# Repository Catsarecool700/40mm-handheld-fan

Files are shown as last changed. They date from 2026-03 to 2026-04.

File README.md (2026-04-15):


Measuring only 40x63x68 its a tiny little pain in the ass to solder and put together, mostly because of the 20 tiny fiddly wires that go everywhere but its really cute and loud so thats all that matters

The code is a mess but functions and the cad is (probably) final 

- Electronics required 
  - Esp32 s3 super mini
  - Mini360 or similar buck converter
  - 128x32 0.92" i2c oled
  - PSP 1000 joystick (the one with pads on the bottom)
  - USBc Trigger board either adjustable or set to 12v
  - Delta [GFC0412D](https://www.delta-fan.com/Download/Spec/GFC0412DS-SM06B0G.pdf) 
  - A diode may be needed if your buck converter lacks one to prevent voltage backflow when programing the esp32
- Hardware required
  - M2x3x3.2 heatset insert X4
  - M2x8 cap head bolt X2
  - M2x3 button head bolt X2
  - M3x25 cap head bolt X4
  - Hot glue gun
- Future plans
  - Website for remote control over wifi
  - Better oled ui with proper menus and a nicer look
  - Mk ii using an even louder and faster spinning fan in the same footprint 

 
 


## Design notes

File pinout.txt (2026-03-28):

1.intake pwm
2.intake tacho
3.exhaust pwm
4.exhaust tacho
5.SCL
6.SDA
9.Y(up/down)
10.X(left/right

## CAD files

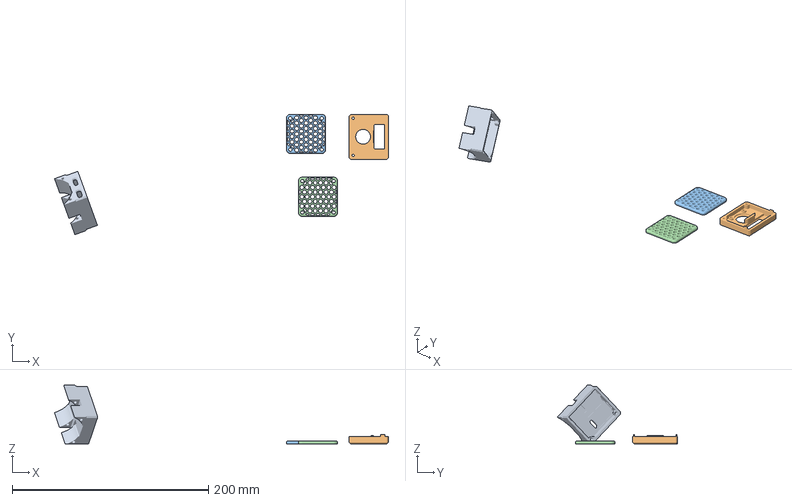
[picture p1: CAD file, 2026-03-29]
STLs/main body.3mf
340.3 x 122.6 x 59.6 mm
main body.stl
Top.stl
grill.stl x 2

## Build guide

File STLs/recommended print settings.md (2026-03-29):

The recomeneded settings for the main body are 
- Automatic tree supports
- 14mm outer brim
- Any infill and wall count (I used 15% gyroid with 3 walls)

I found the optimal printing angle for the main body was a 45* angle, orient the model so that the fully chamfered corner is the only part touching the buildplate then add 2 large manual support dots to the side for support.

 

The other pieces are far less picky with their placement so you can just lay them flat on their largest face

The recomeneded settings for everything else is 
- No supports
- No brim
- 20% gyroid infill and 3 walls (feel free to use more of either though)



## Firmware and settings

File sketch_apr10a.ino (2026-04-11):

// This code is built from various code examples from the following places
// https://dronebotworkshop.com/esp32-pwm-fan/, https://www.espboards.dev/blog/ssd1306-esp32-s3-super-mini-setup/, https://www.teachmemicro.com/using-the-esp32-internal-temperature-sensor-with-arduino/
static const uint8_t woe[512] = {
    0x00, 0x00, 0x00, 0x00, 0x00, 0x00, 0x00, 0x00, 0x00, 0x00, 0x00, 0x00, 0x00, 0x00, 0x00, 0x00, 
    0x00, 0x00, 0x00, 0x00, 0x00, 0x00, 0x00, 0x00, 0x00, 0x00, 0x00, 0x00, 0x00, 0x00, 0x00, 0x00, 
    0x00, 0x00, 0x00, 0x00, 0x00, 0x00, 0x00, 0x00, 0x00, 0x00, 0x00, 0x00, 0x00, 0x00, 0x00, 0x00, 
    0x00, 0xfe, 0x00, 0x00, 0x00, 0x3f, 0x10, 0x01, 0xf8, 0x00, 0x0f, 0xc0, 0x00, 0x00, 0x00, 0x00, 
    0x00, 0xfe, 0x00, 0x00, 0x00, 0x4c, 0xb0, 0x01, 0x88, 0x00, 0x0c, 0xe0, 0x00, 0x00, 0x00, 0x00, 
    0x00, 0x0c, 0x30, 0x61, 0xce, 0x0c, 0x3c, 0x39, 0x81, 0xc4, 0x4c, 0x76, 0x88, 0x1e, 0x79, 0xf0, 
    0x00, 0x18, 0xf9, 0xf3, 0xdf, 0x0c, 0x3e, 0xfd, 0xfb, 0xe6, 0xcc, 0x37, 0xcc, 0x7e, 0xfd, 0xf8, 
    0x00, 0x30, 0xdd, 0xbb, 0x11, 0x0c, 0x22, 0xcd, 0x86, 0x33, 0x8c, 0x36, 0x1e, 0x67, 0xcd, 0x98, 
    0x00, 0x60, 0xc1, 0x83, 0x11, 0x0c, 0x22, 0xc1, 0x86, 0x33, 0x8c, 0x36, 0x36, 0x67, 0x8d, 0x98, 
    0x00, 0xe0, 0xc1, 0x83, 0x11, 0x0c, 0x22, 0xc1, 0x86, 0x37, 0x8c, 0x66, 0x63, 0x3f, 0xcd, 0x98, 
    0x01, 0xfe, 0xf9, 0xf3, 0x1f, 0x0c, 0x22, 0xfd, 0x83, 0xe4, 0xcf, 0xc6, 0x3f, 0x7e, 0xfd, 0xb0, 
    0x00, 0x0e, 0x78, 0xf0, 0x0e, 0x0c, 0x20, 0x79, 0x81, 0xc4, 0x4f, 0x06, 0x19, 0x7e, 0x79, 0xa0, 
    0x00, 0x00, 0x00, 0x00, 0x00, 0x00, 0x00, 0x01, 0x00, 0x00, 0x00, 0x00, 0x00, 0xc6, 0x00, 0x00, 
    0x00, 0x00, 0x00, 0x00, 0x00, 0x00, 0x00, 0x00, 0x00, 0x00, 0x00, 0x00, 0x00, 0xe6, 0x00, 0x00, 
    0x00, 0x00, 0x00, 0x00, 0x00, 0x00, 0x00, 0x00, 0x00, 0x00, 0x00, 0x00, 0x00, 0x78, 0x00, 0x00, 
    0x00, 0x00, 0x00, 0x00, 0x00, 0x00, 0x00, 0x00, 0x00, 0x00, 0x00, 0x00, 0x00, 0x00, 0x00, 0x00, 
    0x00, 0x00, 0x00, 0x00, 0x00, 0x00, 0x00, 0x00, 0x00, 0x00, 0x00, 0x00, 0x00, 0x00, 0x00, 0x00, 
    0x00, 0x00, 0x00, 0x00, 0x00, 0x00, 0x00, 0x00, 0x00, 0x00, 0x00, 0x00, 0x00, 0x00, 0x00, 0x00, 
    0x00, 0x00, 0x00, 0x00, 0x00, 0x00, 0x00, 0x00, 0x00, 0x00, 0x00, 0x00, 0x00, 0x00, 0x00, 0x00, 
    0x01, 0x81, 0x80, 0x00, 0x00, 0x00, 0x00, 0x00, 0x00, 0x00, 0x00, 0x00, 0x00, 0x00, 0x00, 0x00, 
    0x01, 0x99, 0x80, 0x00, 0x00, 0x00, 0x00, 0x00, 0x00, 0x00, 0x00, 0x00, 0x00, 0x00, 0x00, 0x00, 
    0x01, 0x99, 0x98, 0x78, 0x00, 0x00, 0x00, 0x00, 0x00, 0x00, 0x00, 0x00, 0x00, 0x00, 0x00, 0x00, 
    0x00, 0x99, 0x3c, 0xcc, 0x00, 0x00, 0x00, 0x00, 0x00, 0x00, 0x00, 0x00, 0x00, 0x00, 0x00, 0x00, 
    0x00, 0xff, 0x66, 0xfc, 0x00, 0x00, 0x00, 0x00, 0x00, 0x00, 0x00, 0x00, 0x00, 0x00, 0x00, 0x00, 
    0x00, 0xe7, 0x66, 0xc0, 0x00, 0x00, 0x00, 0x00, 0x00, 0x00, 0x00, 0x00, 0x00, 0x00, 0x00, 0x00, 
    0x00, 0x42, 0x3c, 0xcc, 0x00, 0x00, 0x00, 0x00, 0x00, 0x00, 0x00, 0x00, 0x00, 0x00, 0x00, 0x00, 
    0x00, 0x42, 0x38, 0x7c, 0x00, 0x00, 0x00, 0x00, 0x00, 0x00, 0x00, 0x00, 0x00, 0x00, 0x00, 0x00, 
    0x00, 0x00, 0x00, 0x00, 0x00, 0x00, 0x00, 0x00, 0x00, 0x00, 0x00, 0x00, 0x00, 0x00, 0x00, 0x00, 
    0x00, 0x00, 0x00, 0x00, 0x00, 0x00, 0x00, 0x00, 0x00, 0x00, 0x00, 0x00, 0x00, 0x00, 0x00, 0x00, 
    0x00, 0x00, 0x00, 0x00, 0x00, 0x00, 0x00, 0x00, 0x00, 0x00, 0x00, 0x00, 0x00, 0x00, 0x00, 0x00, 
    0x00, 0x00, 0x00, 0x00, 0x00, 0x00, 0x00, 0x00, 0x00, 0x00, 0x00, 0x00, 0x00, 0x00, 0x00, 0x00, 
    0x00, 0x00, 0x00, 0x00, 0x00, 0x00, 0x00, 0x00, 0x00, 0x00, 0x00, 0x00, 0x00, 0x00, 0x00, 0x00
};

#include <Wire.h>
#include <Adafruit_GFX.h>
#include <Adafruit_SSD1306.h>
#include <WiFi.h>
#include <WebServer.h>
#define I2C_SCL 5
#define I2C_SDA 6
#define VRY_PIN  9
#define VRX_PIN  10
#define BUTTON 7
#define SCREEN_WIDTH 128 // display width,  in pixels
#define SCREEN_HEIGHT 32 // display height, in pixels
Adafruit_SSD1306 display(SCREEN_WIDTH, SCREEN_HEIGHT, &Wire, -1);
const char* ap_ssid = "of_course_it_needs_wifi";      // WiFi network name
WebServer server(80);  // NEW: Create web server object on port 80
const int PWM_PIN = 1; 
const int TACH_PIN = 2;  
const int PWM_PIN2 = 3;   
const int TACH_PIN2 = 4;  
const int PWM_FREQ = 25000;    // 25 kHz frequency for computer fans
const int PWM_RESOLUTION = 8;  // 8-bit resolution (0-255)
int valueX = 0; // to store the X-axis value
int valueY = 0; // to store the Y-axis value
volatile unsigned long tachPulseCount = 0;
volatile unsigned long tachPulseCount2 = 0;
unsigned long lastTachTime = 0;
unsigned long lastTachTime2 = 0;
const unsigned long TACH_SAMPLE_TIME = 500;  // Sample period in milliseconds
const unsigned long TACH_SAMPLE_TIME2 = 500;
int rpm = 0;
int rpm2 = 0;
int pwmValue = 0;
int fanspeedPercent = 0;
unsigned long temp_celsius = 0;
int lastState = 0; 
int currentState;
unsigned long buttonPressTime = 0;
bool buttonHeld = false;
bool webServerEnabled = true;
bool webServerInitialized = false;
void IRAM_ATTR tachISR() {
  tachPulseCount = tachPulseCount + 1;
}
void IRAM_ATTR tachISR2() {
  tachPulseCount2 = tachPulseCount2 + 1;
}

void setup() {
  // Start Serial Monitor
  Serial.begin(115200);
  pinMode(BUTTON, INPUT_PULLUP);
  analogSetAttenuation(ADC_11db);
  Wire.begin(I2C_SDA, I2C_SCL);
  if (!display.begin(SSD1306_SWITCHCAPVCC, 0x3C)) {
    Serial.println(F("yo shit fucked"));
    while (1);
  }
  display.clearDisplay();
  display.drawBitmap(0, 0, woe, 128, 32, 1);
  display.display(); 
  delay(3000);         // wait two seconds for initializing
  display.clearDisplay(); // clear display
  ledcAttach(PWM_PIN, PWM_FREQ, PWM_RESOLUTION);
  ledcAttach(PWM_PIN2, PWM_FREQ, PWM_RESOLUTION);
  pinMode(TACH_PIN, INPUT_PULLUP);
  attachInterrupt(digitalPinToInterrupt(TACH_PIN), tachISR, FALLING);
  pinMode(TACH_PIN2, INPUT_PULLUP);
  attachInterrupt(digitalPinToInterrupt(TACH_PIN2), tachISR2, FALLING);
  ledcWrite(PWM_PIN, 0);
  ledcWrite(PWM_PIN2, 0);
  lastTachTime = millis();
  lastTachTime2 = millis();
  
  wifi();
}

void loop() {
  checkButtonHold();  // ADD THIS LINE - Check for button hold first
  currentState = digitalRead(BUTTON);
  Serial.print(currentState);
  valueX = analogRead(VRX_PIN);
  valueY = analogRead(VRY_PIN);
  tacho();
  oled();
  pwm();
  temp_celsius = temperatureRead();
  pwmValue = map(fanspeedPercent, 0, 100, 0, 255);
  ledcWrite(PWM_PIN, pwmValue);
  ledcWrite(PWM_PIN2, pwmValue);
  if (webServerEnabled && webServerInitialized) {
    server.handleClient();
  }
  if (!webServerEnabled) {
    delay(10);  // Give CPU a break when server is off
  }
}
void checkButtonHold() {
  if (digitalRead(BUTTON) == LOW) {
    if (buttonPressTime == 0) {
      buttonPressTime = millis();
    }
    else if ((millis() - buttonPressTime) >= 3000 && !buttonHeld) {
      buttonHeld = true;
      
      if (webServerEnabled) {
        // Turn off web server AND WiFi
        server.stop();
        WiFi.mode(WIFI_OFF);  // This actually turns off the WiFi radio
        webServerEnabled = false;
        Serial.println("Web server and WiFi DISABLED");
      } else {
        // Turn WiFi back on and restart server
        WiFi.mode(WIFI_AP);
        WiFi.softAP(ap_ssid);
        server.begin();
        webServerEnabled = true;
        Serial.println("Web server and WiFi ENABLED");
        Serial.print("IP Address: ");
        Serial.println(WiFi.softAPIP());
      }
    }
  } 
  else {
    buttonPressTime = 0;
    buttonHeld = false;
  }
}
void tacho(){
    // Calculate RPM every second
  unsigned long currentTime = millis();
  unsigned long currentTime2 = millis();
  if (currentTime - lastTachTime >= TACH_SAMPLE_TIME) {
    // Calculate RPM (2 pulses per revolution for most fans)
    rpm = (tachPulseCount * 60000) / (TACH_SAMPLE_TIME * 2);
    tachPulseCount = 0;
    lastTachTime = currentTime;
  }
  if (currentTime2 - lastTachTime2 >= TACH_SAMPLE_TIME2) {
    rpm2 = (tachPulseCount2 * 60000) / (TACH_SAMPLE_TIME2 * 2);
    tachPulseCount2 = 0;
    lastTachTime2 = currentTime2;
  }
}

void pwm(){
  if (valueX >= 2200){
    fanspeedPercent = fanspeedPercent + 5;
    fanspeedPercent = constrain(fanspeedPercent, 0, 100);
    Serial.print("Fan Speed: ");
    Serial.print(fanspeedPercent);
    Serial.println("%");
    delay(100);
  }
  if (valueX <= 1000){
    fanspeedPercent = fanspeedPercent - 5;
    fanspeedPercent = constrain(fanspeedPercent, 0, 100);
    Serial.print("Fan Speed: ");
    Serial.print(fanspeedPercent);
    Serial.println("%");
    delay(100);
  }
  if (valueY >= 2400){
    fanspeedPercent = fanspeedPercent - 1;
    fanspeedPercent = constrain(fanspeedPercent, 0, 100);
    Serial.print("Fan Speed: ");
    Serial.print(fanspeedPercent);
    Serial.println("%");
    delay(100);
  }
  if (valueY <= 800){
    fanspeedPercent = fanspeedPercent + 1;
    fanspeedPercent = constrain(fanspeedPercent, 0, 100);
    Serial.print("Fan Speed: ");
    Serial.print(fanspeedPercent);
    Serial.println("%");
    delay(100);
  }
}

void oled(){
  if (currentState == 0){
    display.setTextSize(1);
    display.setCursor(0, 0);
    display.print("IP: ");
    display.println(WiFi.softAPIP());
    if (webServerEnabled) {
      display.setCursor(0, 10);
      display.print("Webserver & wifi: ON ");
    } else {
      display.setCursor(0, 10);
      display.print("Webserver & wifi: OFF");
    }
  } else {
    display.setTextSize(1.3);
    display.setTextColor(WHITE);

    display.setCursor(70, 0);
    display.print("x=");
    display.print(valueX);

    display.setCursor(70, 10);
    display.print("y=");
    display.println(valueY);

    display.setCursor(0, 0);
    display.print(rpm);
    display.println(" RPM-I");

    display.setCursor(0, 10);
    display.print(rpm2);
    display.println(" RPM-E");

    display.setCursor(0, 20);
    display.print(fanspeedPercent);
    display.println("%");

    display.setCursor(30, 20);
    display.print(pwmValue);
    display.println("PWM");

    display.setCursor(70, 20);
    display.print("Temp ");
    display.print(temp_celsius);
    display.println("C");
  }
  display.display();
  delay(50);
  display.clearDisplay();
}

void wifi() {
  // Start ESP32 in Access Point mode (creates its own WiFi network)
  WiFi.softAP(ap_ssid);
  Serial.println("Access Point Started");
  Serial.print("IP Address: ");
  Serial.println(WiFi.softAPIP());
  
  // Define what happens when someone visits the main webpage
  server.on("/", []() {
    // Basic HTML with Arial font and input box
    String html = "<!DOCTYPE html>\n";
    html += "<html>\n";
    html += "<head>\n";
    html += "  <title>OwO :3</title>\n";
    html += "  <meta charset='UTF-8'>\n";
    html += "  <style>\n";
    html += "    body { font-family: Arial, sans-serif; }\n";
    html += "  </style>\n";
    html += "  <script>\n";
    html += "    // Function to send new fan speed to ESP32 when slider moves\n";
    html += "    function updateFanSpeed(value) {\n";
    html += "      fetch('/setFanSpeed?value=' + value);\n";
    html += "      document.getElementById('fanPercent').innerHTML = value + '%';\n";
    html += "      document.getElementById('speedInput').value = value;\n";
    html += "    }\n";
    html += "    \n";
    html += "    // Function to set fan speed from input box\n";
    html += "    function setSpeedFromInput() {\n";
    html += "      var inputValue = document.getElementById('speedInput').value;\n";
    html += "      var speed = parseInt(inputValue, 10);\n";
    html += "      if (!isNaN(speed) && speed >= 0 && speed <= 100) {\n";
    html += "        // Send the value to ESP32\n";
    html += "        fetch('/setFanSpeed?value=' + speed);\n";
    html += "        // Update the displayed percentage\n";
    html += "        document.getElementById('fanPercent').innerHTML = speed + '%';\n";
    html += "        // Update the slider position\n";
    html += "        document.getElementById('slider').value = speed;\n";
    html += "      } else {\n";
    html += "        alert('Please enter a number between 0 and 100');\n";
    html += "      }\n";
    html += "    }\n";
    html += "    \n";
    html += "    // Function to get latest data from ESP32 (updates displays but NOT the input box)\n";
    html += "    function fetchData() {\n";
    html += "      fetch('/data')\n";
    html += "        .then(response => response.json())\n";
    html += "        .then(data => {\n";
    html += "          document.getElementById('rpm1').innerHTML = data.rpm1 + ' RPM';\n";
    html += "          document.getElementById('rpm2').innerHTML = data.rpm2 + ' RPM';\n";
    html += "          document.getElementById('pwm').innerHTML = data.pwm + ' PWM';\n";
    html += "          document.getElementById('fanPercent').innerHTML = data.fanPercent + '%';\n";
    html += "          document.getElementById('temp').innerHTML = data.temp + '°C';\n";
    html += "          document.getElementById('slider').value = data.fanPercent;\n";
    html += "          // IMPORTANT: Do NOT update the input box here!\n";
    html += "        })\n";
    html += "        .catch(error => {\n";
    html += "          console.log('Error fetching data:', error);\n";
    html += "        });\n";
    html += "    }\n";
    html += "    \n";
    html += "    // Allow pressing Enter key in the input box\n";
    html += "    document.addEventListener('DOMContentLoaded', function() {\n";
    html += "      var inputBox = document.getElementById('speedInput');\n";
    html += "      if (inputBox) {\n";
    html += "        inputBox.addEventListener('keypress', function(event) {\n";
    html += "          if (event.key === 'Enter') {\n";
    html += "            event.preventDefault();\n";
    html += "            setSpeedFromInput();\n";
    html += "          }\n";
    html += "        });\n";
    html += "      }\n";
    html += "    });\n";
    html += "    \n";
    html += "    // Auto-refresh data every 1 second\n";
    html += "    setInterval(fetchData, 500);\n";
    html += "  </script>\n";
    html += "</head>\n";
    html += "<body>\n";
    html += "  <h1>Fan Controller</h1>\n";
    html += "  <hr>\n";
    html += "  \n";
    html += "  <h2>Fan 1 (Intake) RPM:</h2>\n";
    html += "  <p id='rpm1'>0 RPM</p>\n";
    html += "  \n";
    html += "  <h2>Fan 2 (Exhaust) RPM:</h2>\n";
    html += "  <p id='rpm2'>0 RPM</p>\n";
    html += "  \n";
    html += "  <h2>PWM Value (0-255):</h2>\n";
    html += "  <p id='pwm'>0 PWM</p>\n";
    html += "  \n";
    html += "  <h2>Fan Speed Percentage:</h2>\n";
    html += "  <p id='fanPercent'>0%</p>\n";
    html += "  \n";
    html += "  <h3>Adjust Fan Speed:</h3>\n";
    html += "  <input type='range' min='0' max='100' value='0' id='slider' onchange='updateFanSpeed(this.value)'>\n";
    html += "  <br><br>\n";
    html += "  <label>Enter Speed (0-100): </label>\n";
    html += "  <input type='number' id='speedInput' min='0' max='100' value='0' step='1'>\n";
    html += "  <button onclick='setSpeedFromInput()'>Set Speed</button>\n";
    html += "  <br><br>\n";
    html += "  \n";
    html += "  <h2>Temperature:</h2>\n";
    html += "  <p id='temp'>0°C</p>\n";
    html += "  \n";
    html += "  <hr>\n";
    html += "</body>\n";
    html += "</html>\n";
    
    server.send(200, "text/html", html);
  });
  
  // NEW: Endpoint that sends data as JSON (for JavaScript to read)
  server.on("/data", []() {
    String json = "{";
    json += "\"rpm1\":" + String(rpm) + ",";
    json += "\"rpm2\":" + String(rpm2) + ",";
    json += "\"pwm\":" + String(pwmValue) + ",";
    json += "\"fanPercent\":" + String(fanspeedPercent) + ",";
    json += "\"temp\":" + String(temp_celsius);
    json += "}";
    server.send(200, "application/json", json);
  });
  
  // NEW: Endpoint that receives new fan speed from the slider or input box
  server.on("/setFanSpeed", []() {
    if (server.hasArg("value")) {
      fanspeedPercent = server.arg("value").toInt();
      fanspeedPercent = constrain(fanspeedPercent, 0, 100);
      Serial.print("Web interface set fan speed to: ");
      Serial.print(fanspeedPercent);
      Serial.println("%");
      server.send(200, "text/plain", "OK");
    } else {
      server.send(400, "text/plain", "Bad Request");
    }
  });
  
  server.begin();
  webServerEnabled = true;
  webServerInitialized = true;
  Serial.println("Web server initialized and started");
}

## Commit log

2026-03-18 The cad shitttt!
    code will come later when i write that shitttt
2026-03-28 Cad is final and code is a mess
2026-03-29 Rename readme.md to recommended print settings.md
2026-03-29 Create main body.3mf
    [main body.3mf]
